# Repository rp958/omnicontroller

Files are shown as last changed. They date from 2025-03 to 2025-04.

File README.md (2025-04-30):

# OmniController

## Description

*OmniController* is an Open Hardware /  Open Source, all-in-one controller.

It was conceived with retrogaming solutions (such as emulators or FPGA) in mind but can accommodate to modern gaming as well. Its main goal is to cover original button layouts of most of the popular console controllers without having to remap buttons or use different controllers when playing games from different consoles libraries.

It uses the [**GP2040-CE**](https://gp2040-ce.info/) firmware which is well known for its [compatibility](https://gp2040-ce.info/usage#input-modes) with most modern and retro platforms as well as its [very low latency](https://gp2040-ce.info/#performance).

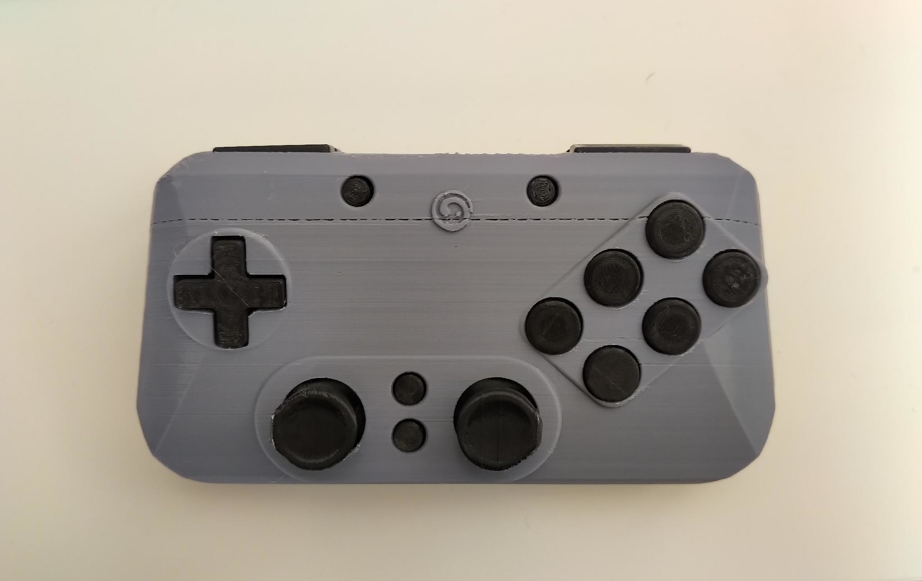
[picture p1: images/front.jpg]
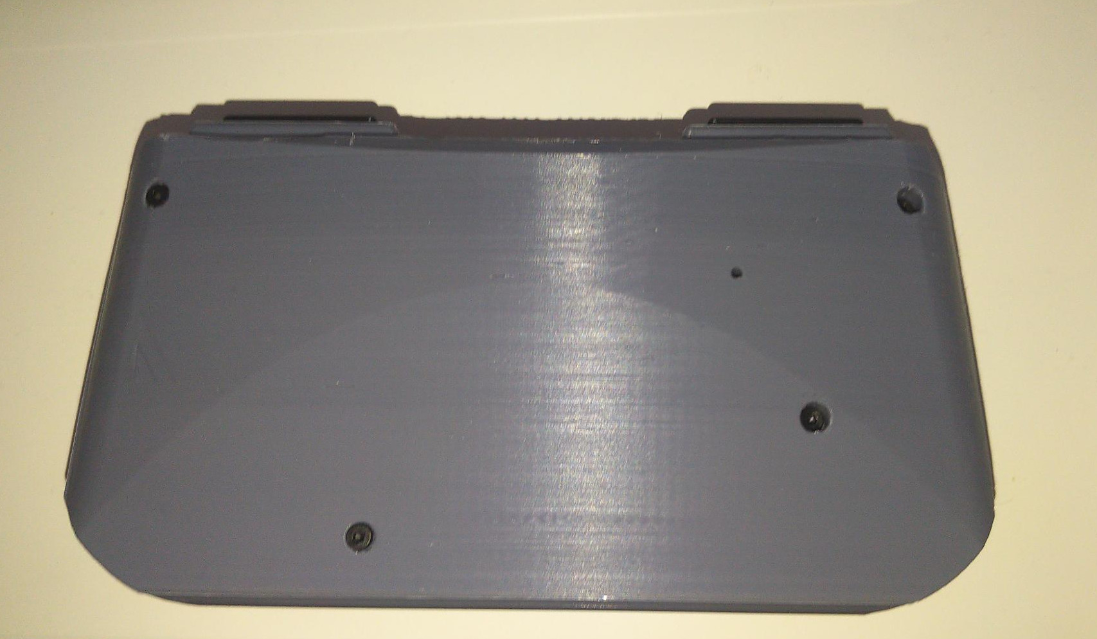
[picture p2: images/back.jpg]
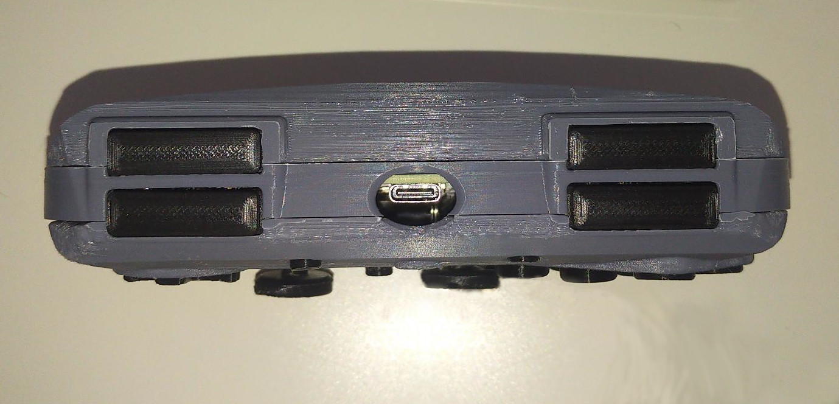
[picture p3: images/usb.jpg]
  

## Default keymap

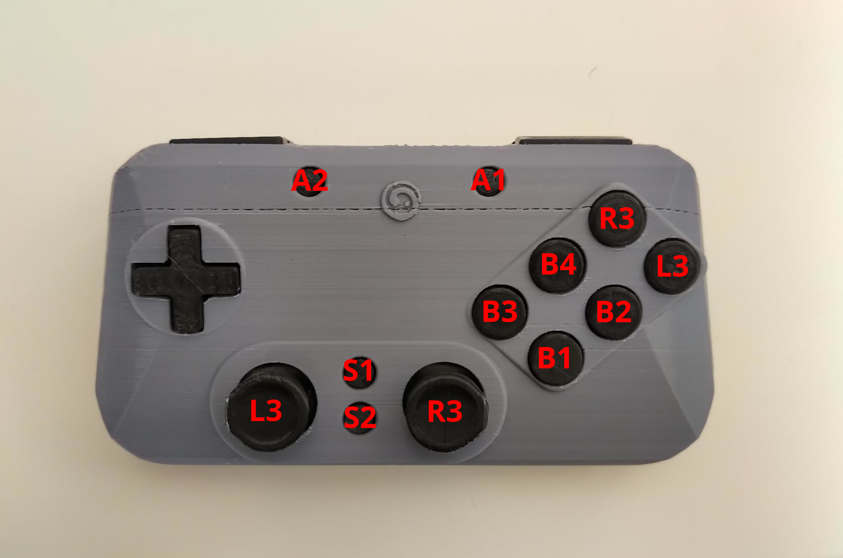
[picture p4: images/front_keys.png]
Front keys.

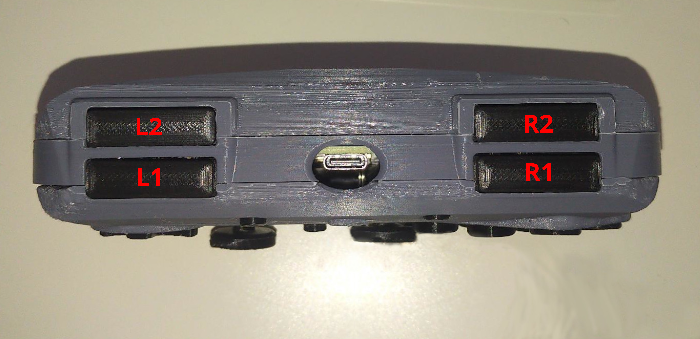
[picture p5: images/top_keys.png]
Back keys.


Please note that the double L3 and R3 buttons (the ones on the joysticks and the face buttons ones) are wired in hardware. That means that if you chose, for exemple, to remap L3 to a different button, both L3s will be remapped to that button. This is due to the fact that all GPIOs available in the firmware/microcontroller are already in use. It is unlikely that you will need to use both joysticks and 6 faces buttons at the same time.

## Getting Started

### Prerequisites

Software:
- Firmware: [**GP2040-CE**](https://gp2040-ce.info/)
- (optional for modifying the PCB): [**KiCAD**](https://www.kicad.org/)
- (optional for modifying the case and buttons): [**FreeCAD**](https://www.freecad.org/)

Hardware:
- 4x M2x4x3.2 threaded inserts
- 4x M2x12 screws
- a soldering iron (to melt the inserts into the case, no actual soldering required)
- super glue
- USB-C cable
- a computer for installing the firmware

### Making the PCB

Download and extract the latest [*OmniController* release](https://github.com/rp958/omnicontroller/releases) file.

All the necessary files for PCB fabrication are located in *release/pcb/*.

Bill of materials:

| Item# | Designation | Manufacturer | Part Number | Package | Value | Quantity |
|---|---|---|---|---|---|---|
| 1 | UP1, DOWN1, LEFT1, RIGHT1, Credit1, Menu1, SEL1, START1, A1, B1, bC1, X1, Y2, Z1, BOOT_SEL1 | Omron Electronics | B3FS-1000P | | | 15 |
| 2 | bR1, bR2, bL1, bL2 | Omron Electronics | B3F-3100 | | | 4 |
| 3 | C1, C2 | | | 0805 (2012 Metric) | 10u capacitor | 2 |
| 4 | C10, C11 | | | 0805 (2012 Metric) | 1u capacitor | 2 |
| 5 | C12, C13, C14, C3, C4, C5, C6, C7, C8, C9 | | | 0805 (2012 Metric) | 100n capacitor | 10 |
| 6 | C15, C16 | | | 0805 (2012 Metric) | 15p capacitor | 2 |
| 7 | LeftStick1, RightStick1 | Alps | RKJXV122400R | (THT) | | 2 | 
| 8 | J1 | G-Switch | GT-USB-7010ASV | | | 1 |
| 9 | R1, R2 | | | 0805 (2012 Metric) | 27.4 ohms resistor | 2 |
| 10 | R3, R4 | | | 0805 (2012 Metric) | 1k resistor | 2 |
| 11 | U1 | Raspberry Pi | RP2040 | QFN-56 7×7mm | | 1 |
| 12 | U2 | Onsemi | NCP1117ST33T3G | SOT-223-3_TabPin2 | | 1 |
| 13 | U3 | Winbond | W25Q128JVSIM | SOIC 208-mil | | 1 |
| 14 | Y1 | Abracon | ABM8-272-T3 | Crystal SMD 3225 4Pin | | 1 |
| 15 | (Optionnal) J2 | GCT | USB1046-GF-0190-L-B-B  | USB_A_Receptacle | | 1 |

NOTE: J2 is only necessary for *Host USB* authentication mode. If not needed, can be left unpopulated.

NOTE: J3 is for development of and does not require populating.

### 3D Printing the case and buttons

You will need to print the following parts (all contained in *release/case/*).

Buttons:
- [ ] 1x dpad_bottom
- [ ] 1x dpad_top
- [ ] 2x joystick
- [ ] 2x button_select_start
- [ ] 2x button_cred_home
- [ ] 4x button_L_R
- [ ] 6x button_face 

Case:
- [ ] 1x case_back
- [ ] 1x case_front
- [ ] 1x middle_frame

For better printing results, it is recommended the following parts be sliced at an angle of 45 degrees and with supports:
- the joysticks
- case_top
- case_bottom

All the other parts should be printed flat and do not require any support.

Please note that depending on the quality and precision of your print, you might have to sand some parts.

### Assembling

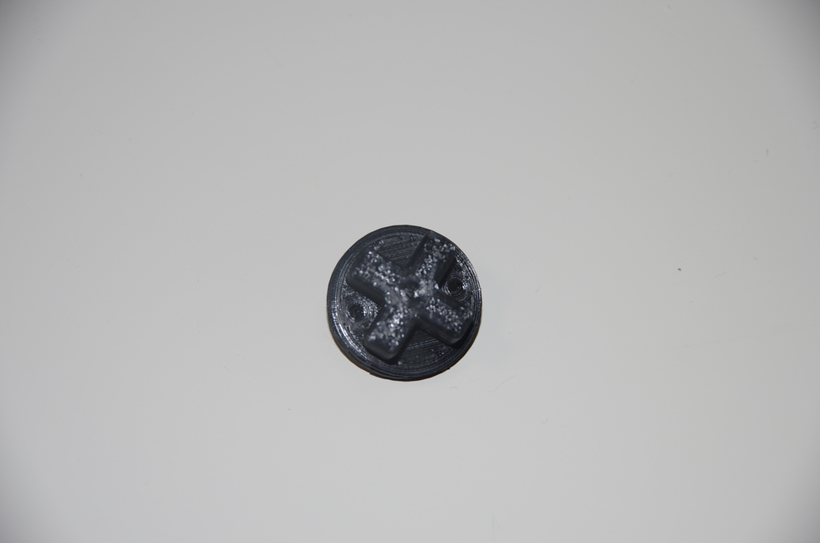
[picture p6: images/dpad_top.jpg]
1. Take the 2 parts of the D-Pad and glue them together back to back, making sure the two holes are aligned. 
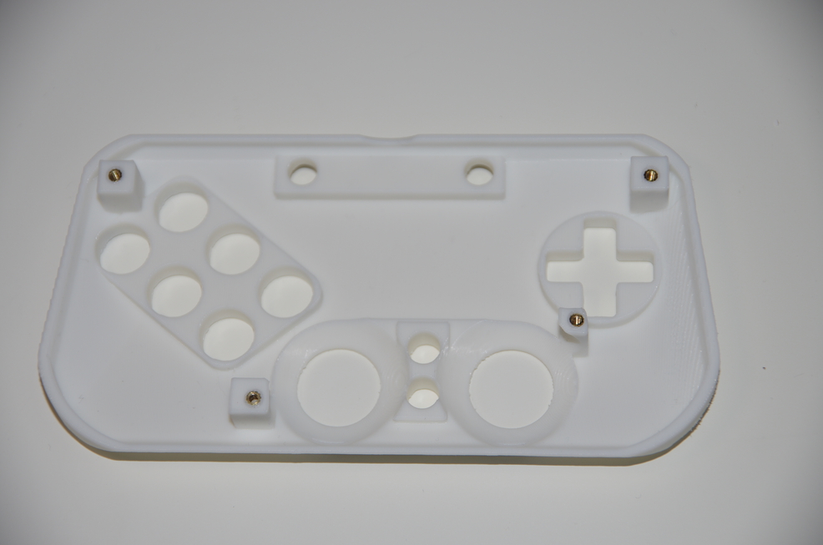
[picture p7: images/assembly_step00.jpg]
2. Take the case front, melt the threaded inserts into the 4 holes using the soldering iron. 
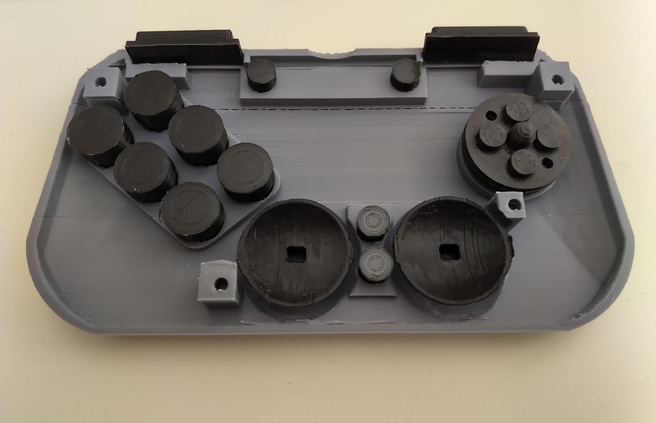
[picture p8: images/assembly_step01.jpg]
3. Place all the face controls as well as L1 and R1 in their respective place. Make sure the rectangular holes in the back of the joysticks are placed horizontally. 
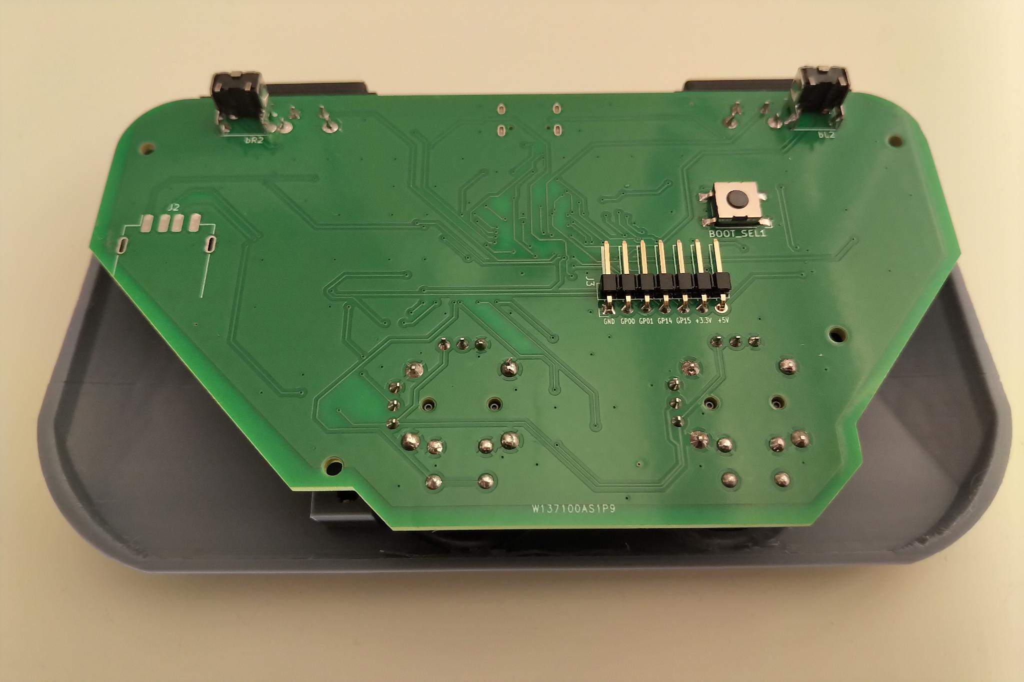
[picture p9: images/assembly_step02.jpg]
4. Place the PCB aligning the holes with the M2 inserts. Make sure the joystick axes go into the rectangular holes. 
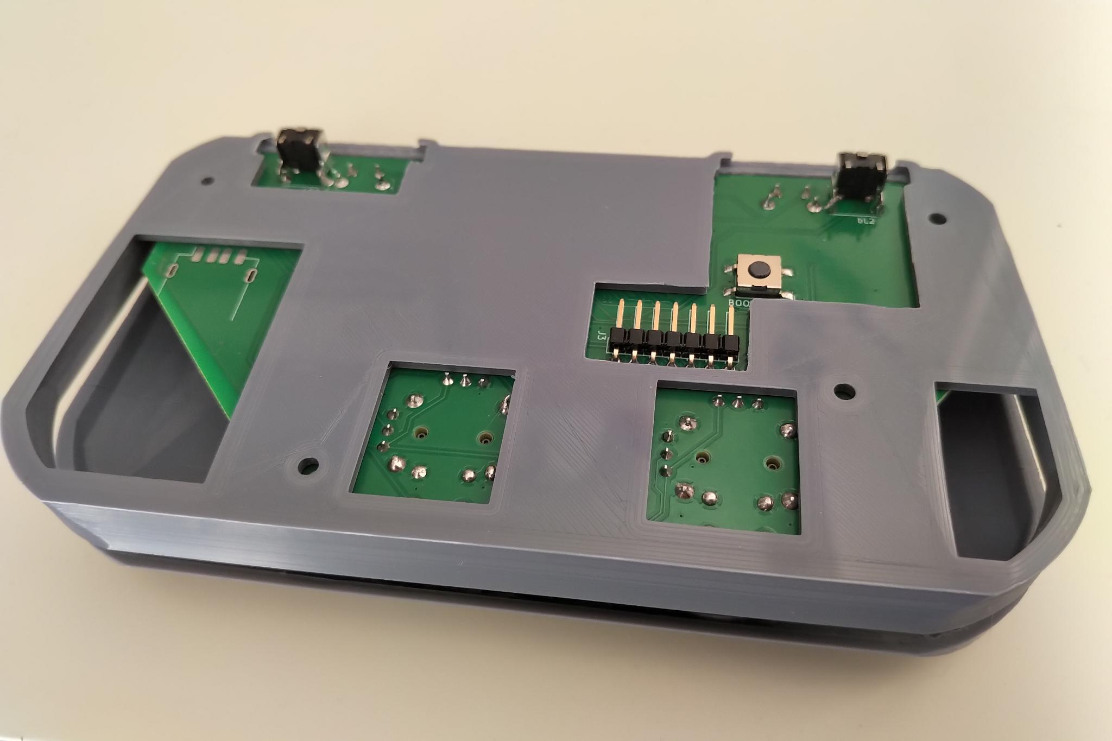
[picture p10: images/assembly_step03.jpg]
5. Insert the middle frame. 
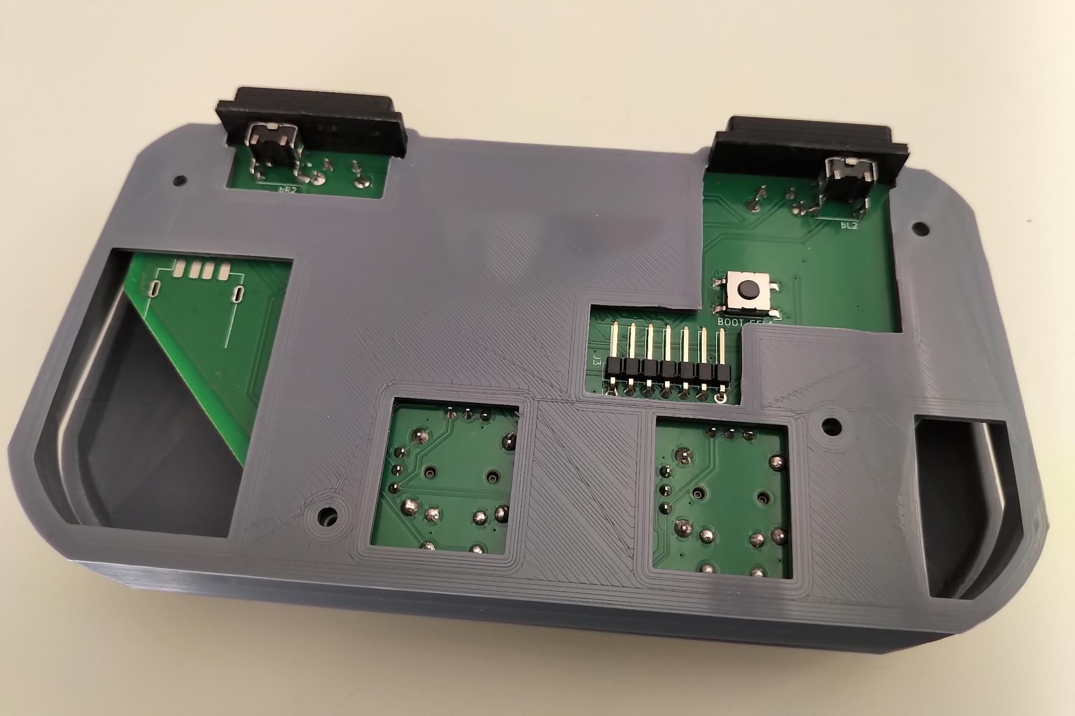
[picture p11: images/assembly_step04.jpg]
6. Place the L2 and R2 buttons. 
7. Close the controller using the back part, then screw it using the 4 M2 screws. Screw them firmly but not too tight. 
8. You're done!

### Flashing the firmware

1. Download the latest version of **GP2040-CE** from the project's [download page](https://gp2040-ce.info/downloads). You must use the link for the **Raspberry Pi Pico** microcontroller.
2. Unplug your controller.
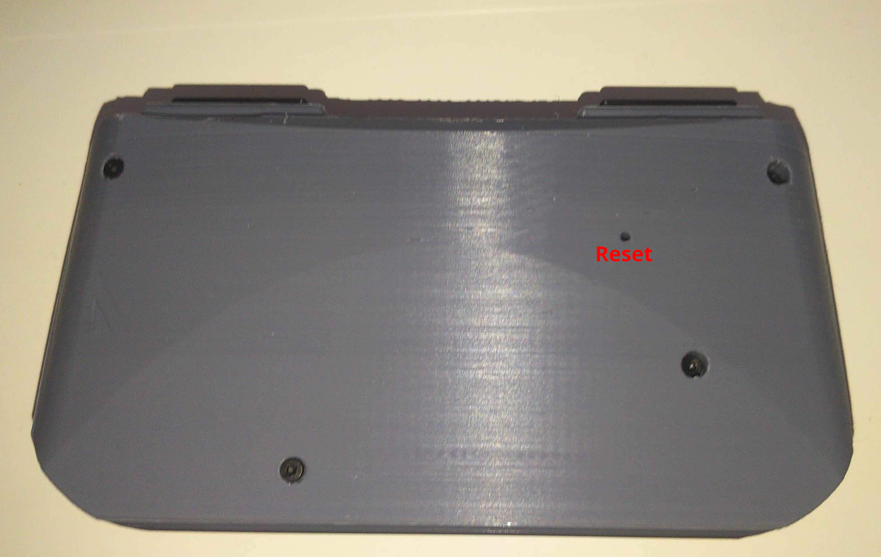
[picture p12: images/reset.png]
3. Use a pin or an unfolded paperclip to press the reset button at the back of the controller. 
4. While pressing the reset button, plug the controller to your computer. Your computer should detect your controller as a mass storage device.
5. Copy the *.uf2* firmware file to the controller memory.
6. Once the file copy is finished, the controller should restart and be detected as an XInput (XBox360) controller by default.

Please refer to the [**GP2040-CE** installation documentation](https://gp2040-ce.info/installation) for more details.

### Recommended configuration

1. Unplug your controller.
2. Download the default [*omnicontroller_default.gp2040*](conf/omnicontroller_default.gp2040) configuration file on your computer.
3. Press and hold the S2 button. While still holding S2, plug the controller to your computer. Your computer should detect your controller as a network adapter.
4. Open the following URL in your Web Browser: [http://192.168.7.1](http://192.168.7.1). This should bring you to the *Web Configurator* interface.
5. Go to *Configuration* > *Data Backup and Restoration*.
6. Click on *Load* and select the *omnicontroller_default.gp2040* file you downloaded at step 2.
7. Click the *REBOOT* button, then *Controller*.

Please refer to the [**GP2040-CE** *Web Configurator* documentation](https://gp2040-ce.info/web-configurator/) for more details.

### Usage
 
Please refer to the [**GP2040-CE** usage documentation](https://gp2040-ce.info/usage)

### Troubleshooting

In case of problems, you can use **Hardware Tester's** [gamepad controller](https://hardwaretester.com/gamepad) in order to make sure you controller is detected correctly and that all buttons are functioning.

## Roadmap

- Several new features are considered, for instance adding an OLED screen, rumble, colord LEDs. Please join the discord via the project's [Patreon](https://www.patreon.com/omnicontroller) for discussing new features and/or new features prioritization.

## Known issues / Limitations

- At this stage, *Host USB* authentication mode for PS4/PS5 is implemented but has not been tester. Please read [*Additionnal PS4 settings*](https://gp2040-ce.info/web-configurator/menu-pages/settings/#additional-ps4-settings) from **GP2040-CE** *Settings* documentation. Any feedback is appreciated.

## License

Distributed under CERN-OHL-S version 2 or later. See [licence text](https://ohwr.org/cern_ohl_s_v2.txt) for more information.

## Contact

Please [e-mail me](mailto:omnicontroller@proton.me) if you want to contribute, especially if you have experience in electronics engineering, CAD or manufacturing.

## Attributions

OmniController uses several KiCAD component footprints and models from the [SnapEDA library](https://www.snapeda.com/parts/).

## Acknowledgments

Many thanks go to the [**GP2040-CE**](https://gp2040-ce.info/) development team.

## Help

If you want to help funding this project, any contribution is greatly welcome. This can help me acquire some prototyping equipment and spend more time on the development. To do so, please use my:

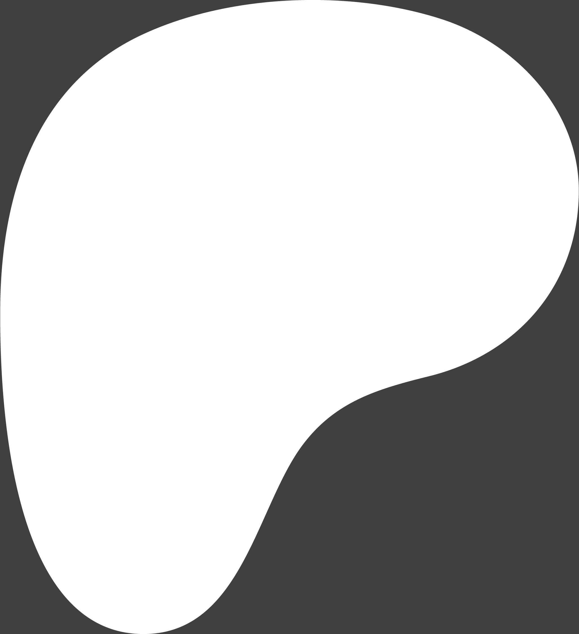
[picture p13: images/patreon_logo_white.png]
- [  Patreon](https://www.patreon.com/omnicontroller) page.
- [  Ko-fi](https://ko-fi.com/omnicontroller) page.

Thank you.

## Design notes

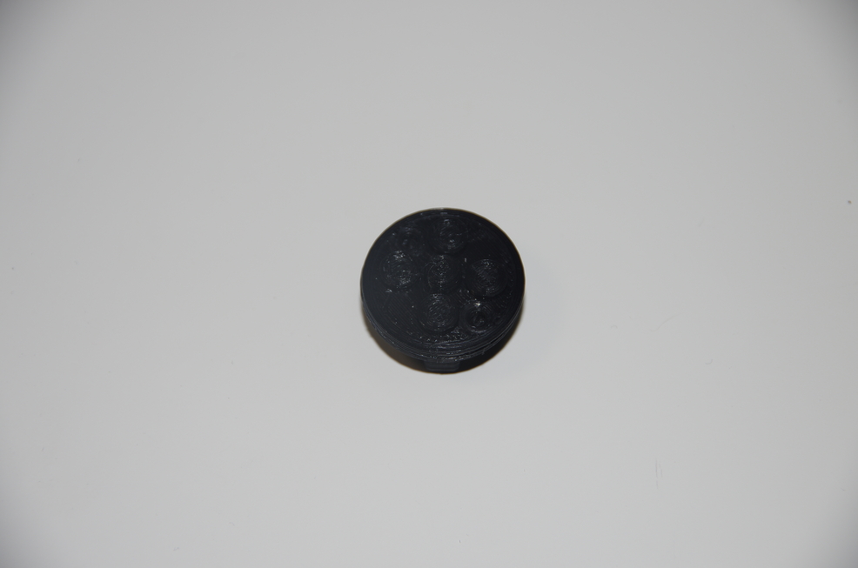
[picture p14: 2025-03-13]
images/dpad_bottom.jpg

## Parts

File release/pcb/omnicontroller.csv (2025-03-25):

Id | Designator | Footprint | Quantity | Designation | Supplier and ref
1 | RightStick1,LeftStick1 | SW_RKJXV122400R | 2 | RKJXV122400R | Alps RKJXV122400R
2 | C8,C6,C13,C5,C7,C14,C4,C9,C3,C12 | C_0805_2012Metric | 10 | 100n | capacitor
3 | Y1 | Crystal_SMD_3225-4Pin_3.2x2.5mm | 1 | ABM8-272-T3 | Abracon ABM8-272-T3
4 | LEFT1,A1,Credit1,B1,SEL1,START1,X1,RIGHT1,DOWN1,Y2,UP1,Menu1,bC1,Z1,BOOT_SEL1 | SW_SPST_Omron_B3FS-100xP | 15 | SW_Omron_B3FS-1000P | Omron B3FS-1000
5 | C1,C2 | C_0805_2012Metric | 2 | 10u | capacitor
6 | J1 | USB_C_Receptacle_G-Switch_GT-USB-7010ASV | 1 | G-Switch GT-USB-7010ASV | G-Switch GT-USB-7010ASV
7 | R1,R2 | C_0805_2012Metric | 2 | 27.4 | resistor
8 | C10,C11 | C_0805_2012Metric | 2 | 1u | capacitor
9 | bR1,bL1,bR2,bL2 | SW_B3F-3100 | 4 | SW_B3F-3100 | omron B3F-3100
10 | U3 | SOIC-8_5.3x5.3mm_P1.27mm | 1 | W25Q128JVSIM | Winbond W25Q128JVSIM
11 | U1 | QFN-56-1EP_7x7mm_P0.4mm_EP3.2x3.2mm | 1 | RP2040 | raspberry
12 | C16,C15 | C_0805_2012Metric | 2 | 15p | capacitor
14 | U2 | SOT-223-3_TabPin2 | 1 | NCP1117ST33T3G | OnSemi NCP1117ST33T3G
15 | R4,R3 | C_0805_2012Metric | 2 | 1k | resistor
16 | J3 | PinHeader_1x07_P2.54mm_Horizontal | 1 | Conn_01x07_Pin | XFCN PZ254R-11-07P
17 | J2 | USB_A_Receptacle_GCT_USB1046 | 1 | USB_A | GCT USB1046-GF-0190-L-B-B

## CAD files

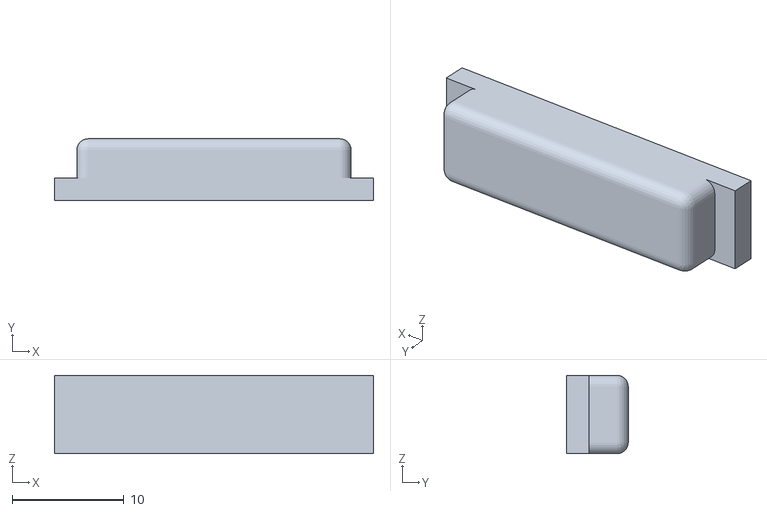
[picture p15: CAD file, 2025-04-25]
release/case/omnicontroller-button_L_R.stl
28.5 x 5.50 x 7.00

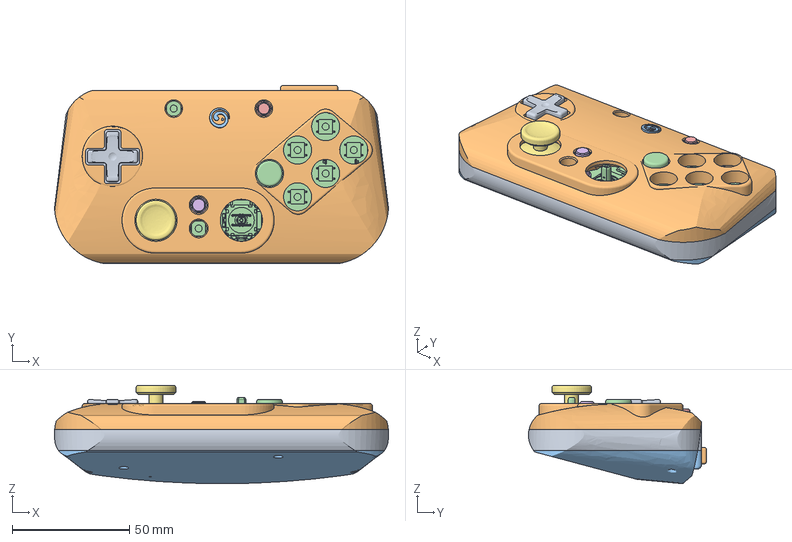
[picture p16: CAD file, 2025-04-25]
src/case/omnicontroller.FCStd
142.7 x 76.1 x 42.0 mm
middle_frame
case_front
case_back
button_face
button_cred_home
button_select_start
joystick
dpad_bottom
dpad_top
button_L_R
Scale001
pcb

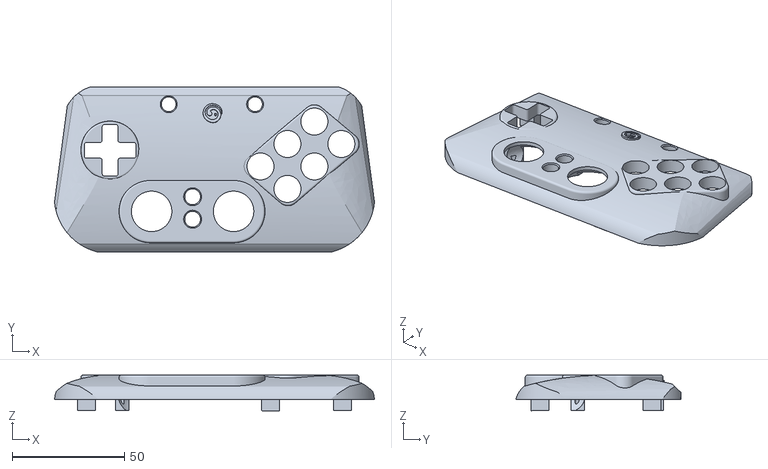
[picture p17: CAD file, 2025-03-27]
release/case/omnicontroller-case_front.stl
142.5 x 73.7 x 16.0

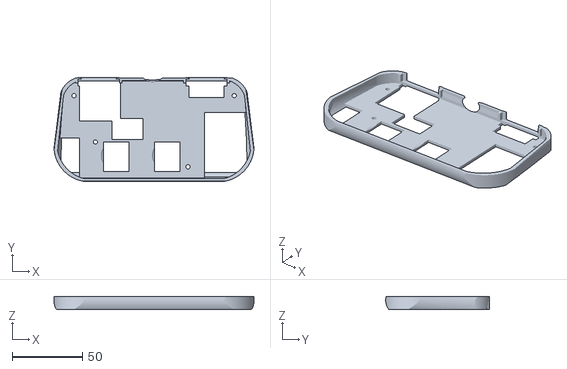
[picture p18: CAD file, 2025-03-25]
release/case/omnicontroller-middle_frame.stl
142.7 x 74.0 x 9.00

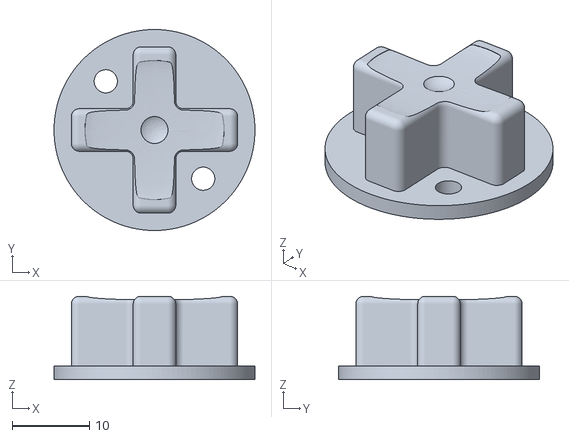
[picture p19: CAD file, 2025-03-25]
release/case/omnicontroller-dpad_top.stl
26.0 x 26.0 x 10.8

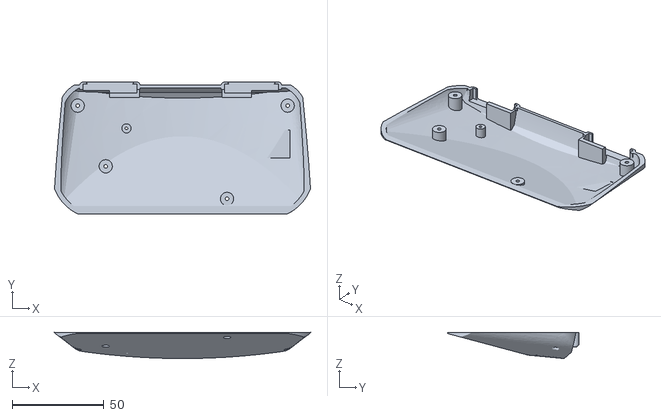
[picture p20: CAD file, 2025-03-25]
release/case/omnicontroller-case_back.stl
139.4 x 71.9 x 14.2

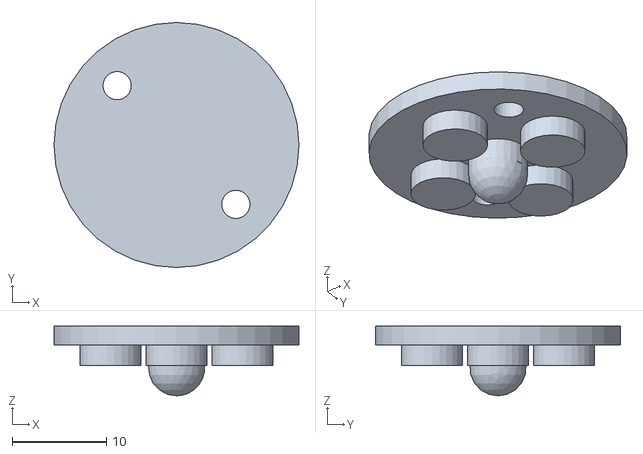
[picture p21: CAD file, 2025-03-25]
release/case/omnicontroller-dpad_bottom.stl
26.0 x 26.0 x 7.40

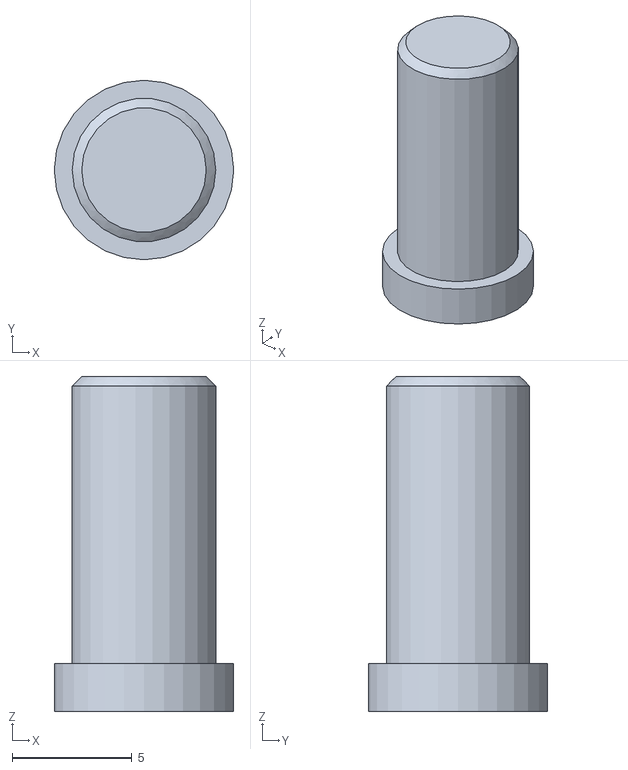
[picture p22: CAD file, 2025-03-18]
release/case/omnicontroller-button_select_start.stl
7.50 x 7.50 x 14.0

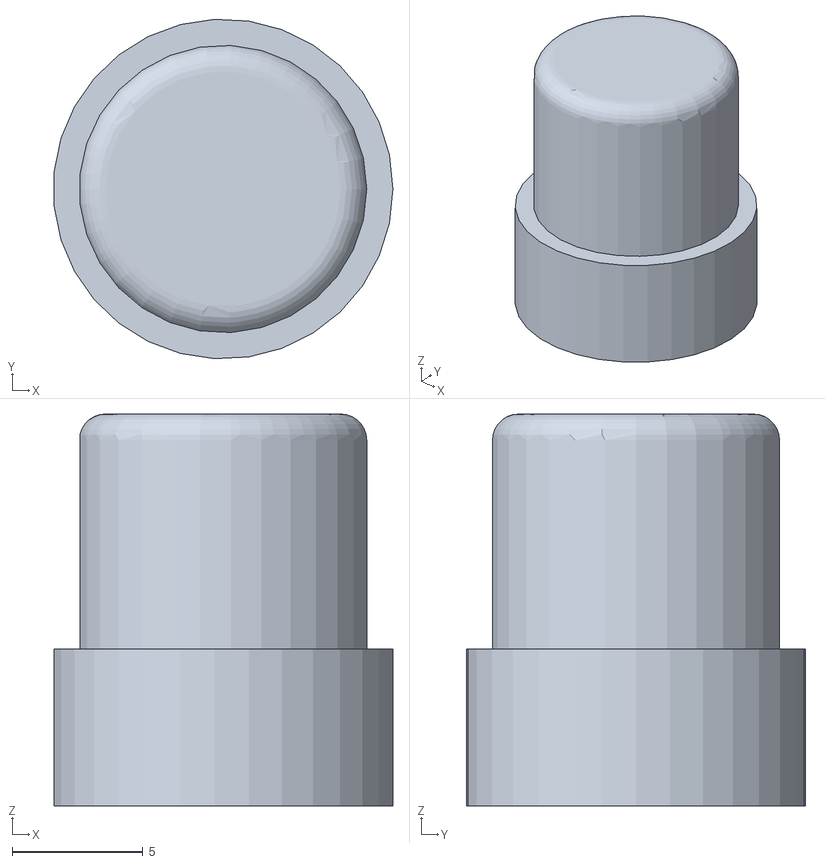
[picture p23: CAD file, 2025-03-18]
release/case/omnicontroller-button_face.stl
13.0 x 13.0 x 15.0

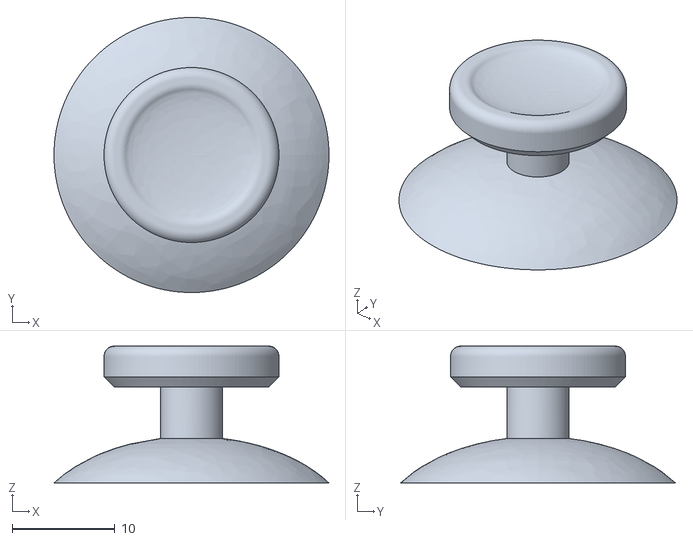
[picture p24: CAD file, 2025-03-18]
release/case/omnicontroller-joystick.stl
26.7 x 26.7 x 13.3

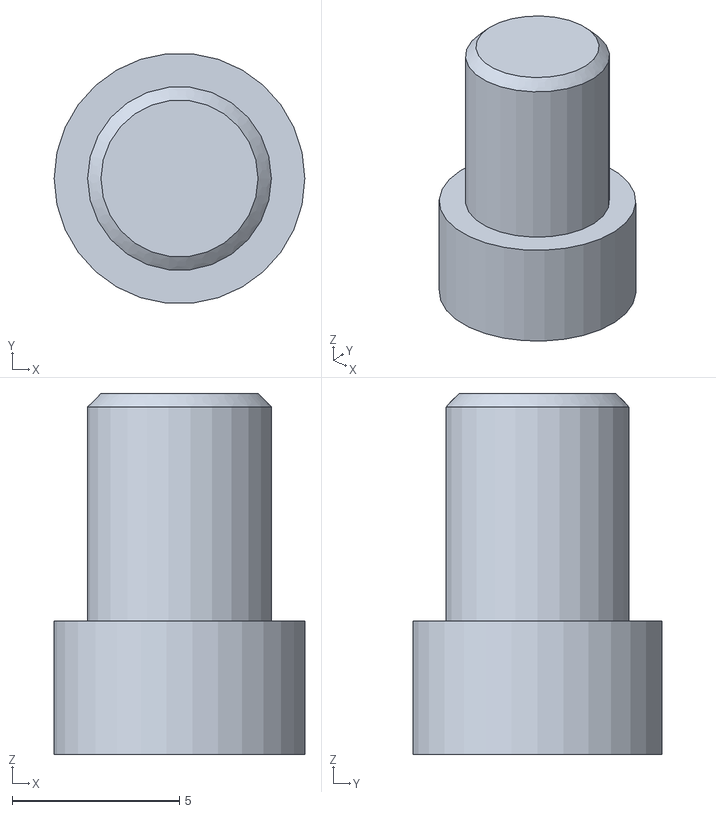
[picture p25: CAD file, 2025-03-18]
release/case/omnicontroller-button_cred_home.stl
7.50 x 7.46 x 10.8

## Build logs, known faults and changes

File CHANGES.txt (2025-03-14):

Anyone modifying the design should provide brief information about the
modifications, including the date they were made

Information about the design should be added but never removed from this
file.

According to section 3.3.b of the licence, licensees should provide a
brief entry with a date and the nature of the modification for each
design change.

2025-03-12 : Initial release.

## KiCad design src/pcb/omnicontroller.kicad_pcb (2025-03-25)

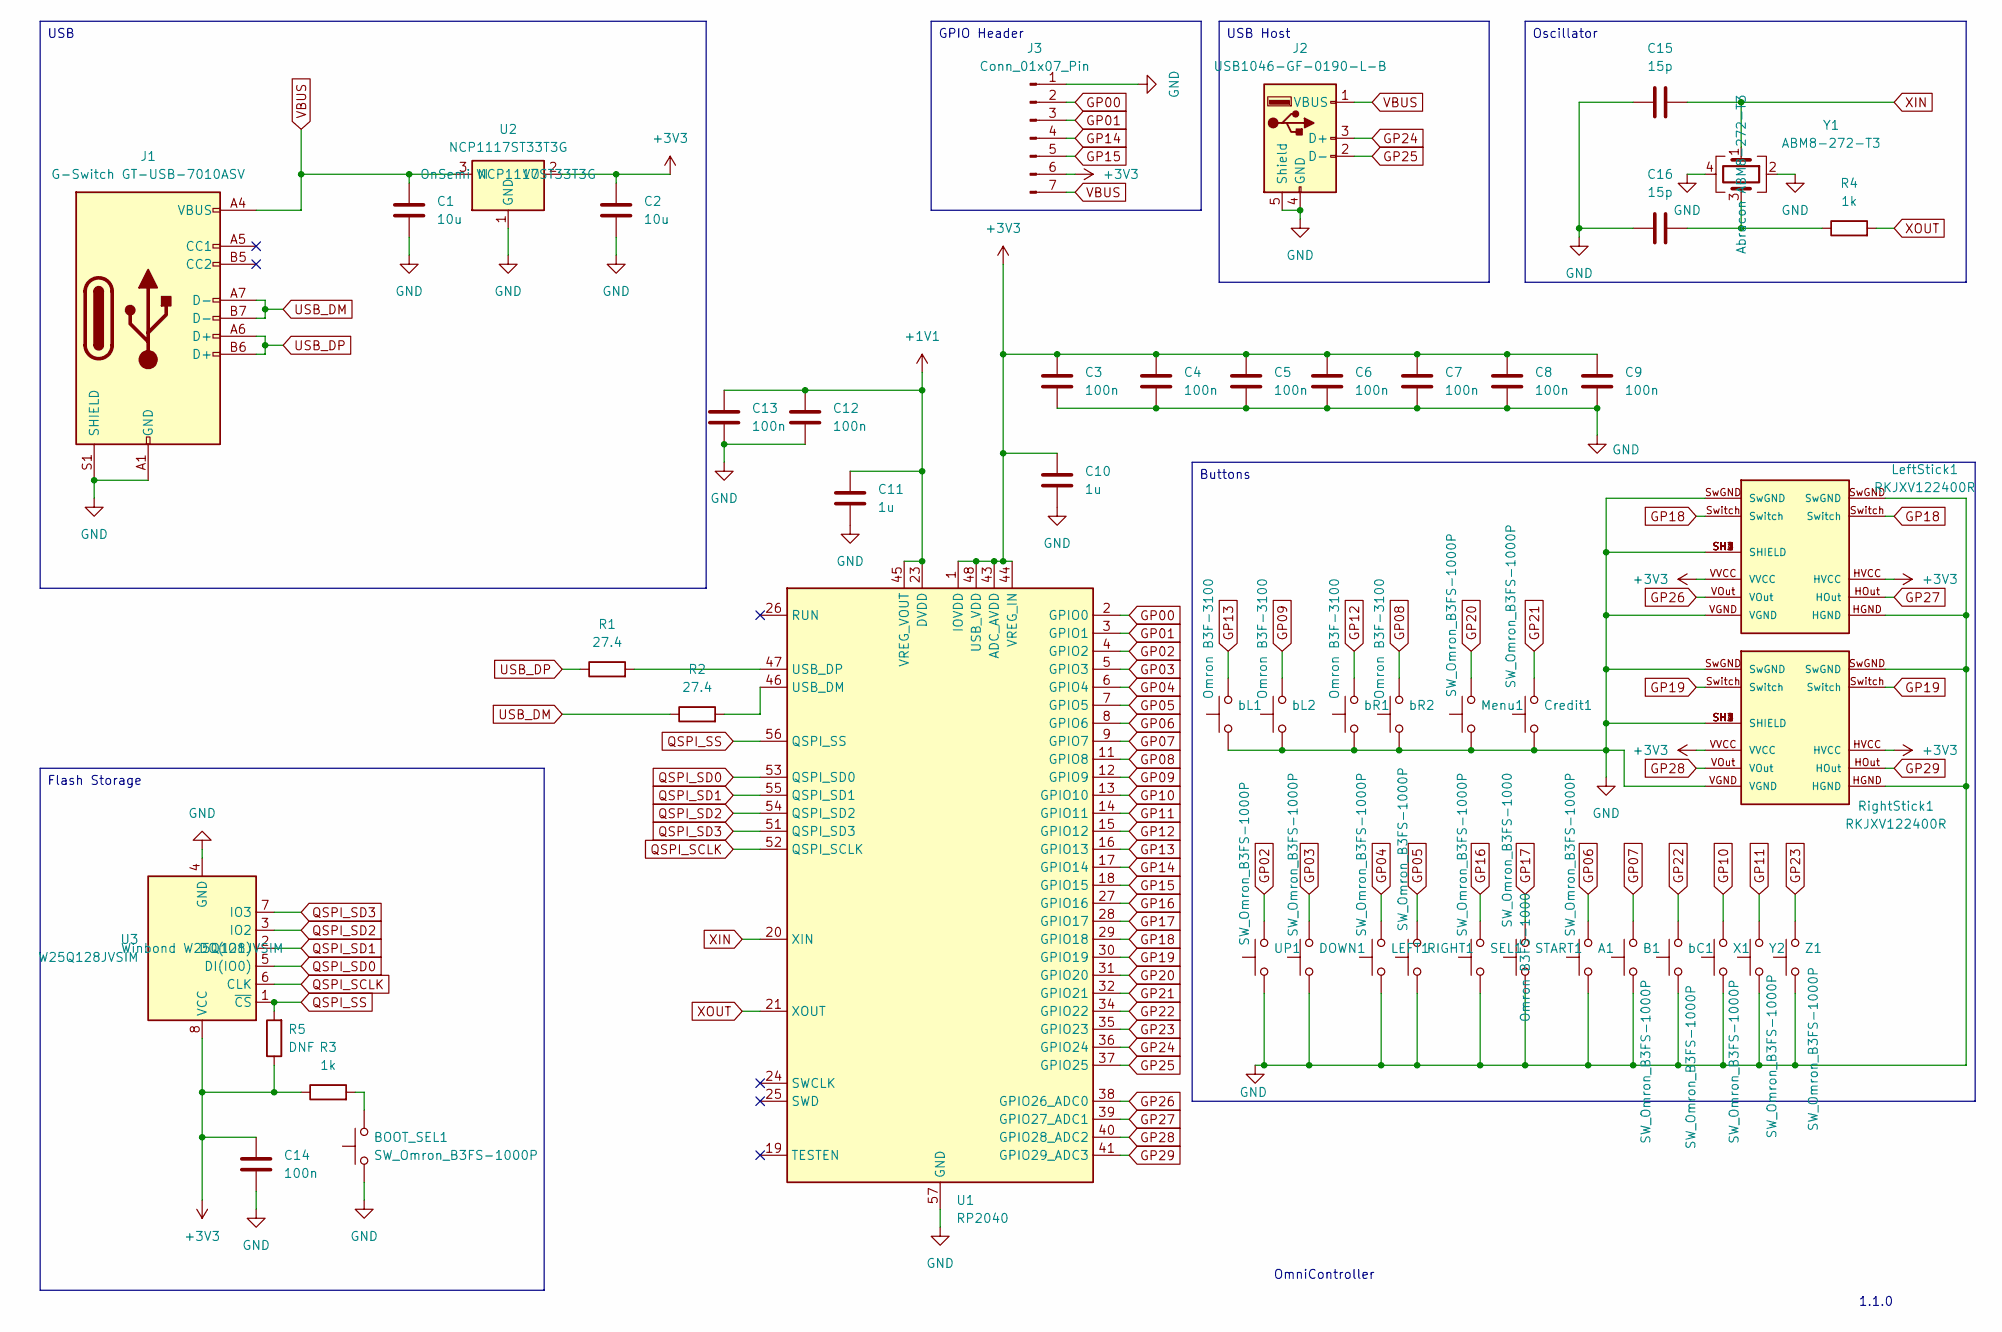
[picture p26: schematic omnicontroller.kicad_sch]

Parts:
A1: SW_Omron_B3FS-1000P; SW_SPST_Omron_B3FS-100xP
B1: SW_Omron_B3FS-1000P; SW_SPST_Omron_B3FS-100xP
BOOT_SEL1: SW_Omron_B3FS-1000P; SW_SPST_Omron_B3FS-100xP
C1, C2: 10u; C_0805_2012Metric
C3, C4, C5, C6, C7, C8, C9, C12, C13, C14: 100n; C_0805_2012Metric
C10, C11: 1u; C_0805_2012Metric
C15, C16: 15p; C_0805_2012Metric
Credit1: SW_Omron_B3FS-1000P; SW_SPST_Omron_B3FS-100xP
DOWN1: SW_Omron_B3FS-1000P; SW_SPST_Omron_B3FS-100xP
J1: G-Switch GT-USB-7010ASV; USB_C_Receptacle_G-Switch_GT-USB-7010ASV
J2: USB1046-GF-0190-L-B; USB_A_Receptacle_GCT_USB1046
J3: Conn_01x07_Pin; PinHeader_1x07_P2.54mm_Horizontal
LEFT1: SW_Omron_B3FS-1000P; SW_SPST_Omron_B3FS-100xP
LeftStick1: RKJXV122400R; SW_RKJXV122400R; PARTREV N/A
Menu1: SW_Omron_B3FS-1000P; SW_SPST_Omron_B3FS-100xP
R1, R2: 27.4; C_0805_2012Metric
R3, R4: 1k; C_0805_2012Metric
R5: DNF; C_0805_2012Metric
RIGHT1: SW_Omron_B3FS-1000P; SW_SPST_Omron_B3FS-100xP
RightStick1: RKJXV122400R; SW_RKJXV122400R; PARTREV N/A
SEL1: SW_Omron_B3FS-1000P; SW_SPST_Omron_B3FS-100xP
START1: SW_Omron_B3FS-1000; SW_SPST_Omron_B3FS-100xP
U1: RP2040; QFN-56-1EP_7x7mm_P0.4mm_EP3.2x3.2mm
U2: NCP1117ST33T3G; SOT-223-3_TabPin2
U3: W25Q128JVSIM; SOIC-8_5.3x5.3mm_P1.27mm
UP1: SW_Omron_B3FS-1000P; SW_SPST_Omron_B3FS-100xP
X1: SW_Omron_B3FS-1000P; SW_SPST_Omron_B3FS-100xP
Y1: ABM8-272-T3; Crystal_SMD_3225-4Pin_3.2x2.5mm
Y2: SW_Omron_B3FS-1000P; SW_SPST_Omron_B3FS-100xP
Z1: SW_Omron_B3FS-1000P; SW_SPST_Omron_B3FS-100xP
bC1: SW_Omron_B3FS-1000P; SW_SPST_Omron_B3FS-100xP
bL1, bL2: SW_B3F-3100
bR1, bR2: SW_B3F-3100

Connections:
+1V1: C11.1, C12.1, C13.1, U1.23 (DVDD), U1.45 (VREG_VOUT), U1.50 (DVDD)
GND: A1.1, B1.1, BOOT_SEL1.1, C1.2, C2.2, C3.2, C4.2, C5.2, C6.2, C7.2, C8.2, C9.2, C10.2, C11.2, C12.2, C13.2, C14.2, C15.1, C16.1, Credit1.1, DOWN1.1, J1.A1 (GND), J1.A12 (GND), J1.B1 (GND), J1.B12 (GND), J1.S1 (SHIELD), J2.4 (GND), J2.5 (Shield), J3.1, LEFT1.1, LeftStick1.HGND, LeftStick1.SH1 (SHIELD), LeftStick1.SH2 (SHIELD), LeftStick1.SH3 (SHIELD), LeftStick1.SH4 (SHIELD), LeftStick1.SwGND, LeftStick1.VGND, Menu1.1, RIGHT1.1, RightStick1.HGND, RightStick1.SH1 (SHIELD), RightStick1.SH2 (SHIELD), RightStick1.SH3 (SHIELD), RightStick1.SH4 (SHIELD), RightStick1.SwGND, RightStick1.VGND, SEL1.1, START1.1, U1.57 (GND), U2.1 (GND), U3.4 (GND), UP1.1, X1.1, Y1.2, Y1.4, Y2.1, Z1.1, bC1.1, bL1.1, bL2.1, bR1.1, bR2.1
GP00: J3.2, U1.2 (GPIO0)
GP01: J3.3, U1.3 (GPIO1)
GP02: U1.4 (GPIO2), UP1.2
GP03: DOWN1.2, U1.5 (GPIO3)
GP04: LEFT1.2, U1.6 (GPIO4)
GP05: RIGHT1.2, U1.7 (GPIO5)
GP06: A1.2, U1.8 (GPIO6)
GP07: B1.2, U1.9 (GPIO7)
GP08: U1.11 (GPIO8), bR2.2
GP09: U1.12 (GPIO9), bL2.2
GP10: U1.13 (GPIO10), X1.2
GP11: U1.14 (GPIO11), Y2.2
GP12: U1.15 (GPIO12), bR1.2
GP13: U1.16 (GPIO13), bL1.2
GP14: J3.4, U1.17 (GPIO14)
GP15: J3.5, U1.18 (GPIO15)
GP16: SEL1.2, U1.27 (GPIO16)
GP17: START1.2, U1.28 (GPIO17)
GP18: LeftStick1.Switch, U1.29 (GPIO18)
GP19: RightStick1.Switch, U1.30 (GPIO19)
GP20: Menu1.2, U1.31 (GPIO20)
GP21: Credit1.2, U1.32 (GPIO21)
GP22: U1.34 (GPIO22), bC1.2
GP23: U1.35 (GPIO23), Z1.2
GP24: J2.3 (D+), U1.36 (GPIO24)
GP25: J2.2 (D-), U1.37 (GPIO25)
GP26: LeftStick1.VOut, U1.38 (GPIO26_ADC0)
GP27: LeftStick1.HOut, U1.39 (GPIO27_ADC1)
GP28: RightStick1.VOut, U1.40 (GPIO28_ADC2)
GP29: RightStick1.HOut, U1.41 (GPIO29_ADC3)
unnamed: BOOT_SEL1.2, R3.2
unnamed: C16.2, R4.1, Y1.3
unnamed: R2.2, U1.46 (USB_DM)
unnamed: R1.2, U1.47 (USB_DP)
QSPI_SCLK: U1.52 (QSPI_SCLK), U3.6 (CLK)
QSPI_SD0: U1.53 (QSPI_SD0), U3.5 (DI(IO0))
QSPI_SD1: U1.55 (QSPI_SD1), U3.2 (DO(IO1))
QSPI_SD2: U1.54 (QSPI_SD2), U3.3 (IO2)
QSPI_SD3: U1.51 (QSPI_SD3), U3.7 (IO3)
USB_DM: J1.A7 (D-), J1.B7 (D-), R2.1
USB_DP: J1.A6 (D+), J1.B6 (D+), R1.1
VBUS: C1.1, J1.A4 (VBUS), J1.A9 (VBUS), J1.B4 (VBUS), J1.B9 (VBUS), J2.1 (VBUS), J3.7, U2.3 (VI)
XIN: C15.2, U1.20 (XIN), Y1.1
XOUT: R4.2, U1.21 (XOUT)

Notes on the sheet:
1.1.0
OmniController
Flash Storage
Buttons
USB
USB Host
Oscillator
GPIO Header

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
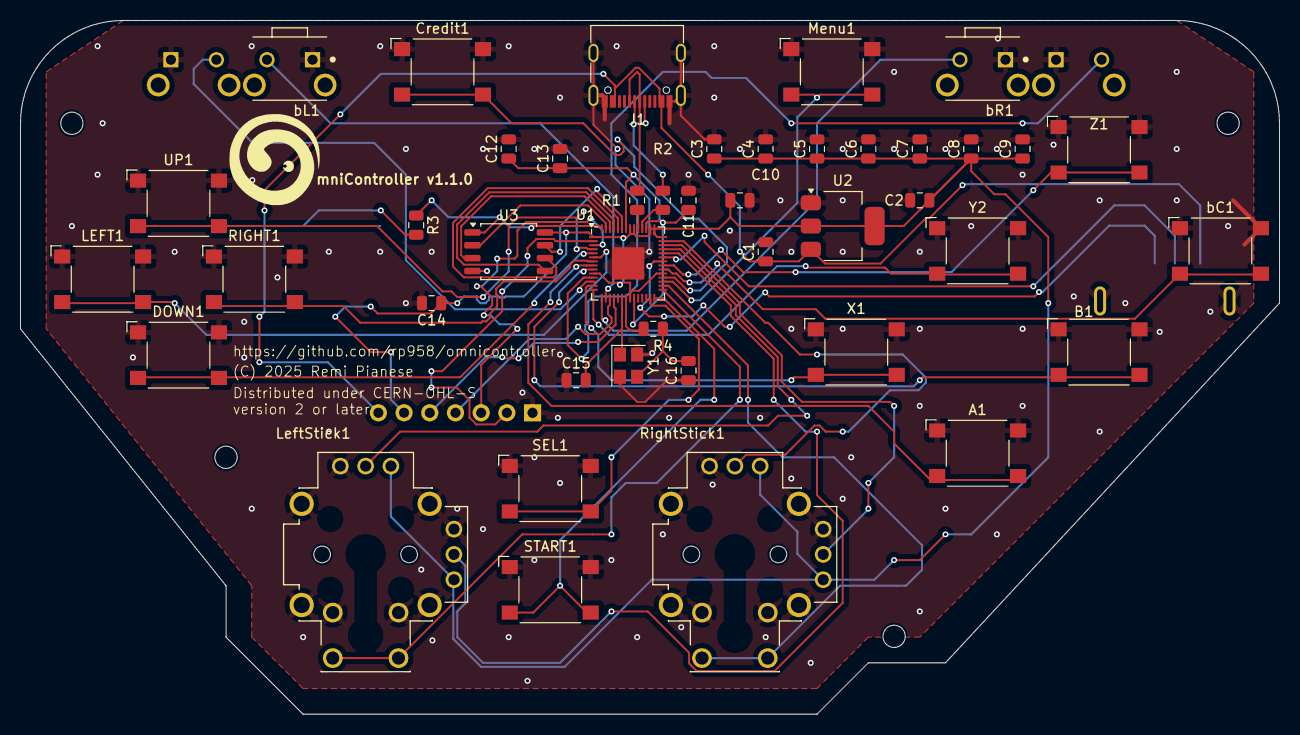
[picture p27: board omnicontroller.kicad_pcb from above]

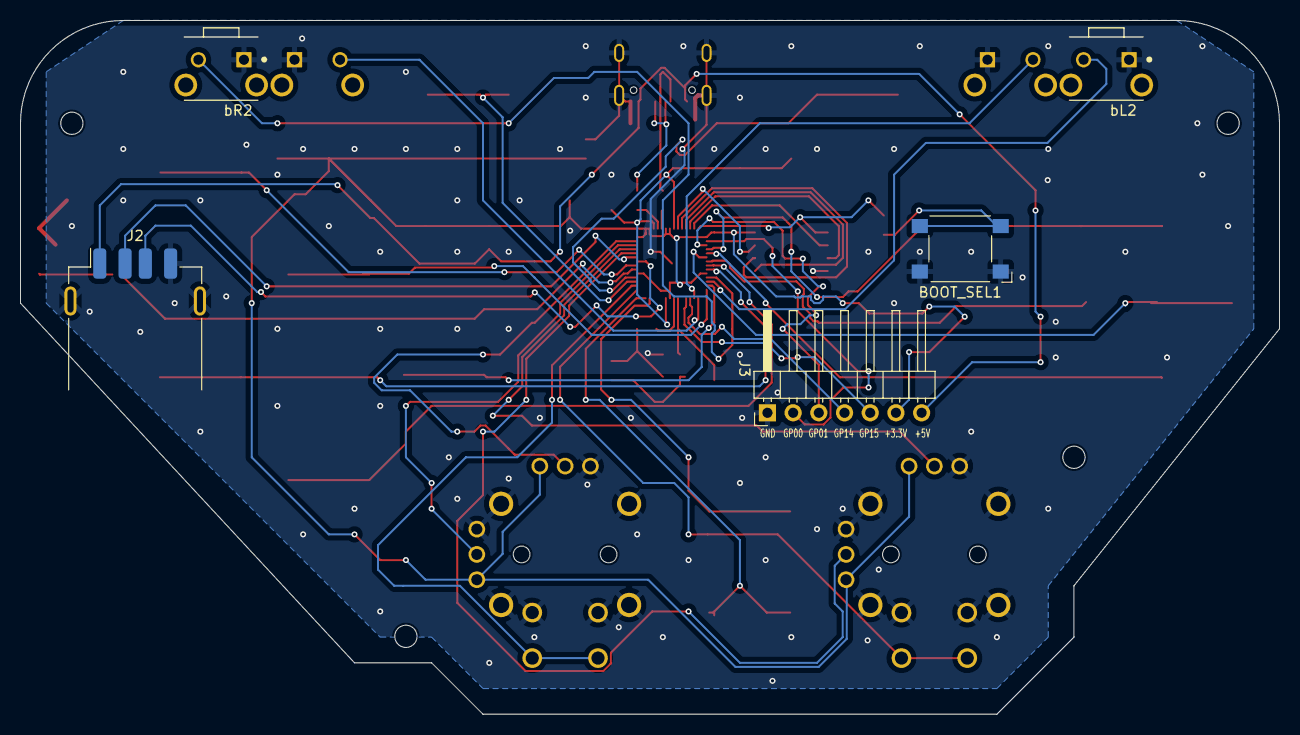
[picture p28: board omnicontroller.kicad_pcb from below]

Board: 2 copper layers, 124.5 x 68.6 mm, 48 parts (5 on the bottom side), 48 nets.

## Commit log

2025-03-13 add pcb
    [omnicontroller.kicad_pcb, omnicontroller.kicad_sch]
2025-03-14 Add freecad project with case and buttons
2025-03-18 convert to kicad 9.0 file format
    [omnicontroller.kicad_pcb, omnicontroller.kicad_sch]
2025-03-18 add RKJXV122400 footprint
    [omnicontroller.kicad_pcb]
2025-03-18 fix some drc warnings
    [omnicontroller.kicad_pcb]
2025-03-18 add release files
    [omnicontroller-B_Cu.gbr, omnicontroller-B_Mask.gbr, omnicontroller-B_Paste.gbr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]
2025-03-21 move L1,L2, R1 and R2 buttons to top side
    replace B3FS-1000 with B3F-3100 for those buttons
    [omnicontroller.kicad_pcb, omnicontroller.kicad_sch]
2025-03-21 add omron B3F-3100 footprint
2025-03-21 connect buttons C and Z to GPIO 22 and 23
    [omnicontroller.kicad_pcb, omnicontroller.kicad_sch]
2025-03-21 add USB A port for PS4/5 host mode authentication
    [omnicontroller.kicad_pcb, omnicontroller.kicad_sch]
2025-03-22 add pinheader with all unused GPIO
    [omnicontroller.kicad_pcb, omnicontroller.kicad_sch]
2025-03-22 Add 3d models to pcb
    [omnicontroller.kicad_pcb]
2025-03-25 update usb A connector
    [omnicontroller.kicad_pcb, omnicontroller.kicad_sch]
2025-03-25 update pcb release files
    [omnicontroller-B_Cu.gbr, omnicontroller-B_Mask.gbr, omnicontroller-B_Paste.gbr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]
2025-03-25 import v1.1.0 of pcb + adjust dpad button alignment
2025-03-25 add pcb mesh file
2025-03-25 modify case to fit GPIO pin connector and host USB connectore
2025-03-25 move L1,L2, R1 and R2 buttons on top side (printable case and buttons)
2025-03-25 update case and buttons release files
    [omnicontroller-button_L_R.stl, omnicontroller-case_back.stl, omnicontroller-case_front.stl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]
2025-03-27 update front release file
    [omnicontroller-case_front.stl]
2025-04-25 Adjust shoulder buttons size
    [omnicontroller.FCStd]
2025-04-25 Update release file
    [omnicontroller-button_L_R.stl]
2025-04-30 Add missing component footprints and 3D models

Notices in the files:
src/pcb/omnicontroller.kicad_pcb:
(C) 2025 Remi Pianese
